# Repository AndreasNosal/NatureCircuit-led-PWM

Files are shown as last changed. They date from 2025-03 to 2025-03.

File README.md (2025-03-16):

# Mobile-Controlled Light

This project showcases a light fixture that can be controlled remotely via a smartphone (using ESP32 and BLE/Wi-Fi). The device is designed for flexible operation and easy assembly, making it suitable for a wide range of DIY enthusiasts or educational projects. By incorporating a custom PCB, an LED panel, and 3D-printed parts, you can create a smart lighting system that connects seamlessly to your mobile phone.

Originally designed to help users learn about PCB assembly, soldering techniques, and microcontroller programming, this project emphasizes a hands-on approach. Whether you order your PCBs from JLCPCB and print your own stencil for the LED panel or simply 3D-print the housing at home, you’ll gain valuable experience in hardware assembly and coding for an IoT-focused device.

Our webside for instructions: https://nature-circuit.tech/courses

## Features
- **ESP32-Based Controller**: Uses two main files (`main.py` and `ble_advertising.py`) to establish a reliable Bluetooth connection for receiving commands from your smartphone.
- **LED Panel**: Powered by an optional custom PCB or a standard LED strip; easily replaceable or upgradable.
- **3D-Printable Enclosure**: Designed for FDM printing with minimal supports. Can also be adapted to various 3D printers.
- **Scalable Assembly**: Choose between ordering a stencil for solder paste application or printing your own with a standard 3D printer.
- **Easy Soldering**: Ideal for beginners; the main PCB has through-hole or straightforward SMD components, and the layout is beginner-friendly.
- **Flexible Power Input**: Operates on typical USB power or a regulated supply (e.g., 5V).  

## Getting Started
1. **Gather Materials**: Order or produce the main PCB (recommended via JLCPCB) and LED panel. If you own a 3D printer, you can create the stencil for solder paste application.  
2. **Print Enclosure**: Use your preferred 3D printer and slicer settings (e.g., minimal supports). PLA or PETG are commonly used filaments.  
3. **Solder Components**: Prepare your soldering iron (typically 320–350 °C). Follow the silkscreen labels on the PCB and reference any documentation or schematics for correct polarity and placement.  
4. **Program the ESP32**:  
   - Upload `main.py` and `ble_advertising.py` to the ESP32 board.  
   - `main.py` runs automatically on reboot.  
   - `ble_advertising.py` enables BLE connectivity so the device can receive commands.  
5. **Assemble & Power Up**: Once everything is in place, provide power (5V recommended), and check the device’s functionality by connecting with your mobile phone.

## Usage
- **Mobile App Connection**: Use a compatible app (or custom-developed one) to scan and connect via BLE.  
- **Light Control**: Toggle the light on/off or adjust brightness (if supported).  
- **Firmware Updates**: Modify `main.py` for custom behavior, color transitions, scheduling, or advanced IoT integration.

## License
- Under **GPL-3.0** license.

## Example in Action
led-box-preview-video

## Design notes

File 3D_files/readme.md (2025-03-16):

# 3D Files for PWM-Light

This folder contains the **3D models** (Fusion 360 design files, STL exports, and any additional resources) used to create the enclosure or other mechanical parts for the **PWM-light** project. The models are designed to be **FDM-friendly**, requiring minimal supports, and are easily adaptable for various 3D printers and use cases.

## Contents

- **Fusion 360 Source Files**  
  - Editable design files for further enhancements or customizations. If you need to change dimensions, mounting points, or aesthetics, simply open these in Autodesk Fusion 360 (or a compatible CAD tool) and modify as needed.

- **STL Files**  
  - Ready-to-print mesh files exported from the Fusion 360 models. These can be opened in your preferred slicing software (e.g., PrusaSlicer, Cura, Simplify3D) to generate G-code for your 3D printer.

- **Additional Docs/Images (if provided)**  
  - Any reference pictures, exploded views, or supplementary instructions specific to assembling the printed parts.
Meteo_box_2025-Mar-16_04-50-34PM-000_CustomizedView15039672676

## Printing Recommendations

- **Minimal Supports**: The models are structured to minimize or even eliminate the need for supports, saving on material and print time.
- **Material Choice**:  
  - **PLA** is a common choice for indoor use, providing ease of printing and cost-effectiveness.  
  - **PETG** is recommended if you need more heat or impact resistance.
- **Infill & Perimeters**: Adjust infill percentage and perimeter count based on your durability requirements. For typical enclosures, an **infill of 10–20%** and 2–3 perimeters often suffice.

## Assembly Notes

1. **Mounting Hardware**: In most cases, M3 screws or self-tapping screws are used to secure boards, panels, or lids.  
2. **Access to Ports & Vents**: Ensure your final print properly aligns with cutouts for cables, power, or ventilation.  
3. **Combining with Electronics**: This enclosure is specifically designed for the **PWM-light** PCB and related components as described in the main repository. However, you can also adapt it for other electronics if needed.

## Modifying the Design

- The **Fusion 360** files are provided for easy editing.  
- Feel free to **remix** the enclosure to fit different boards, additional sensors, or custom cutouts.  
- If you improve or redesign the models, consider contributing your modifications back to this project!

## Usage & License

- These design files are offered under the **GPL-3.0** license, similar to the rest of the project.  
- You’re free to share, modify, and build upon the designs, as long as you provide the same freedoms to others and acknowledge the original source.
obrázok

---

Enjoy bringing the **PWM-light** enclosure to life! If you encounter any issues during printing or assembly, check the [main documentation](../README.md) or open an issue in the repository. Contributions and feedback are always welcome.

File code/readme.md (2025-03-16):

# PWM-Light Firmware

This repository contains **MicroPython** files for driving a PWM-based light (LED or MOSFET output) via Bluetooth Low Energy (BLE) on **ESP32-C3** microcontrollers. It demonstrates how to advertise and receive BLE messages to control the brightness level or simple on/off actions for connected LEDs.

## Repository Contents

1. **`ble_advertising.py`**  
   - A helper library that enables the ESP32-C3 to broadcast its presence via BLE. It handles the fundamental advertising payload necessary for BLE connections.
2. **`pwm-led-ESP32_C3_SuperMini.py`**  
   - A MicroPython script optimized for the **ESP32-C3 SuperMini** board.  
   - Assigns GPIO pins specific to this board and sets up BLE-based UART to receive commands (e.g., "ON", "OFF", or brightness values).
3. **`pwm-led-Seed-Studio-C3.py`**  
   - A nearly identical MicroPython script for the **Seed-Studio ESP32-C3** board.  
   - The main difference lies in the assigned GPIO pins for the RGB LEDs, MOSFET driver, and optional buzzer.

## How It Works

### BLE Peripheral Setup
Both `pwm-led-ESP32_C3_SuperMini.py` and `pwm-led-Seed-Studio-C3.py` create a **BLESimplePeripheral** instance, which:
- Advertises itself under the name `PWM-LED`.
- Exposes two UART-like characteristics (`RX` and `TX`) so a smartphone or computer can connect via BLE and exchange data.

The advertising functionality is implemented with the help of **`ble_advertising.py`**, which constructs the BLE packets announcing the device’s presence. Once a central device (such as a phone) connects:
- **Writes** to the `RX` characteristic are received by the script (`on_write` callback).
- **Notifications** for the `TX` characteristic can be used to send data back to the central device if needed.

### Command Parsing
Incoming data is decoded in `on_rx(value)`, where text commands are expected:
- `ON` turns on the MOSFET (or LED) at either full brightness or a previously set brightness level.
- `OFF` switches the MOSFET (or LED) fully off.
- Numeric values between **0** and **100** set the duty cycle, effectively controlling brightness (`0`% = off, `100`% = maximum).

### PWM Output & Pin Definitions
- A dedicated **PWM** object controls the MOSFET pin, allowing partial or full brightness adjustments.
- Additional **PWM** objects handle an **RGB LED** (three separate channels for red, green, and blue). These enable pulse/breathing effects while advertising or responding to connection status.
- **Buzzer** feedback:
  - A short ascending tone indicates a **new connection**.
  - A short descending tone indicates a **disconnection**.

### Differences in Board Scripts
The **ESP32-C3 SuperMini** and **Seed-Studio ESP32-C3** boards share similar functionality, but differ in **GPIO pin assignments**:
- `pwm-led-ESP32_C3_SuperMini.py` uses pin constants (`buzzer_gpio`, `mosfet_gpio`, etc.) suitable for the SuperMini layout.
- `pwm-led-Seed-Studio-C3.py` adjusts these pin values for the Seed-Studio layout.

## Getting Started

1. **Set Up MicroPython**:  
   - Flash a MicroPython firmware compatible with your ESP32-C3 board.

2. **Upload Files**:  
   - Use a tool such as **Thonny**, **uPyCraft**, or the **ampy** CLI to upload:
     - `ble_advertising.py`
     - The relevant PWM script for your board:
       - `pwm-led-ESP32_C3_SuperMini.py` **or**  
       - `pwm-led-Seed-Studio-C3.py`
   - Make sure both files reside in the device’s root filesystem.  
   - You may rename the chosen script to `main.py` so it runs on startup, or manually call it from the REPL.

3. **Power the Board**:  
   - Provide a suitable 5V supply (or 3.3V if your board includes a regulator).  
   - Ensure any connected LED strip, MOSFET, or RGB LED is wired properly.

4. **Connect via BLE**:
   - On your smartphone, open a BLE UART app or a custom app.  
   - Find and connect to the device named `PWM-LED`.  
   - Once connected, send commands like `ON`, `OFF`, or a number from `0` to `100`.

5. **Test and Modify**:
   - Observe LED brightness changes and buzzer feedback on connection/disconnection.  
   - Adjust code in the script for custom effects or different pin mappings.

## Example Commands

- **`ON`**: Turn on the LED/MOSFET at the last known brightness level or full.  
- **`OFF`**: Switch off the LED/MOSFET entirely.  
- **`50`**: Set the LED brightness to 50% (half duty cycle).  

## License
- Under **GPL-3.0** license.

## Further Customizations
- **RGB Effects**: Modify `pulse()` or `blink()` methods in the `RGBleds` class for unique lighting animations.  
- **Buzzer Sounds**: Customize the tones in `sound_connect()` or `sound_disconnect()` for unique connection alerts.  
- **Pin Mapping**: Change the pin constants at the top of each script if you use different GPIO lines or want to port the code to another board.

---  

Enjoy controlling your PWM-based lighting system via BLE! Contributions and suggestions are always welcome.

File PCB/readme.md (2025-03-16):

# PWM-Light PCB

This repository contains the PCB design files and documentation for a **PWM-based light control module**. By using a dedicated PCB, you can drive LEDs or other lighting elements with precise brightness control via PWM (Pulse Width Modulation). The board is ideal for DIY projects, educational use, or as a foundation for more advanced smart-lighting solutions.



## Overview
- **KiCad Design**: The PCB is designed in KiCad (including schematic and layout).  
- **PWM Output**: Provides efficient dimming capability for LED arrays or single LEDs with minimal flicker.  
- **ESP32 or Other Microcontrollers**: Compatible with 3.3V logic devices (e.g., ESP32, STM32, Arduino Pro Mini at 3.3V, etc.) for easy integration into IoT or custom home-automation setups.  
- **Power Handling**: Designed to be supplied from a stable 5V source (or other voltages, depending on your chosen components and regulator configuration).  
- **JLCPCB Manufacturing**: Gerber files are ready to upload to PCB manufacturers (e.g., JLCPCB).  

## Features
- **Compact Layout**: Minimal footprint for easy integration into small enclosures.  
- **Adjustable Voltage Regulation**: Option to include a regulator if powering from higher than 5V.  
- **Through-Hole & SMD Mix**: Balanced design for straightforward soldering—newcomers can assemble basic sections while advanced users can integrate SMD parts for improved performance.  
- **Expansion Headers**: Multiple I/O pins (PWM, I2C, SPI, etc.) broken out for adding sensors or additional modules.

## Getting Started

1. **Download or Clone the Repository**  
   - Access the KiCad project files and Gerber exports from this repository.

2. **Customize the Design (Optional)**  
   - If you want different connectors, pinouts, or layout modifications, edit the schematic and PCB layout in KiCad.  
   - Generate new Gerber files if you make changes.

3. **Order the PCB**  
   - Upload the provided Gerber files to a PCB manufacturer such as JLCPCB.  
   - Choose your PCB specifications (layer count, color, thickness, etc.).  
   - Wait for the boards to be manufactured and shipped.



4. **Assemble the Components**  
   - Refer to the schematic/BoM (Bill of Materials) for correct part placement.  
   - Solder the components using standard soldering techniques.  
     - For SMD parts, you may use solder paste and a reflow method (hot plate, reflow oven, or hot air gun).  
     - For through-hole parts, use a temperature of around 320–350 °C and ensure solid, shiny joints.

5. **Program & Connect**  
   - If using an ESP32 or similar microcontroller, attach it to the board’s headers or pads.  
   - Upload your firmware (e.g., Arduino, MicroPython) to control PWM signals and logic.  
   - Power the board with a stable 5V supply (or according to your regulator setup).

6. **Test & Calibrate**  
   - Connect an LED array or single LED to the PWM output pins.  
   - Vary the duty cycle in your code to confirm proper dimming functionality.  
   - Check power consumption, heat dissipation, and general performance.

## Usage Scenarios
- **Smart Lighting**: Combine with a Bluetooth or Wi-Fi module for mobile app control.  
- **DIY Projects**: Enhance desk lamps, ambient room lighting, or artistic LED installations.  
- **Educational**: Demonstrate PWM principles and advanced lighting control in classroom or workshop settings.

## License
- Licensed under the **GPL-3.0** License.
> *Feel free to share improvements or fork this project to fit your specific needs. Contributions are welcome!*

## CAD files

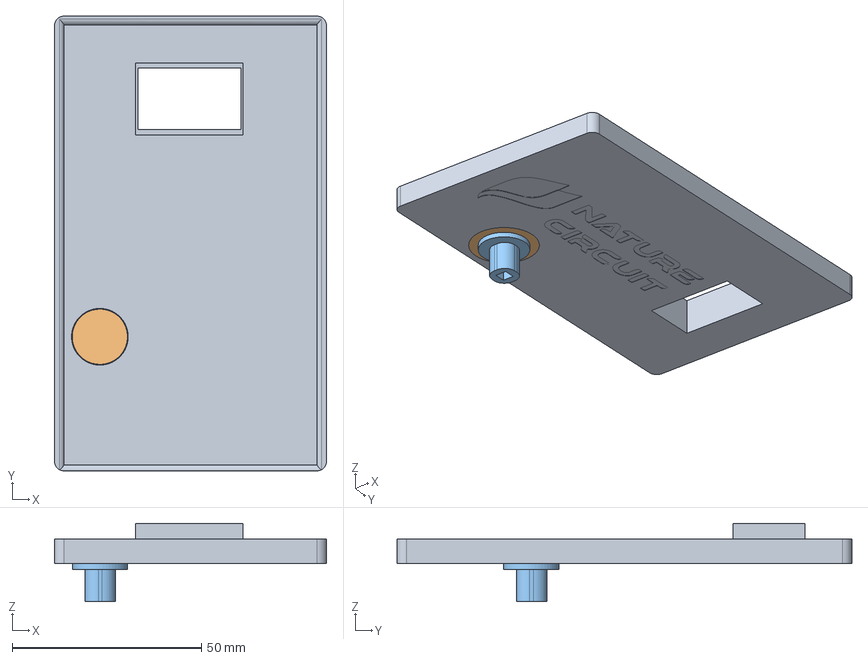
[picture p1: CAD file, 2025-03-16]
3D_files/LED_BOX_top v29.step
71.9 x 120.2 x 20.6 mm

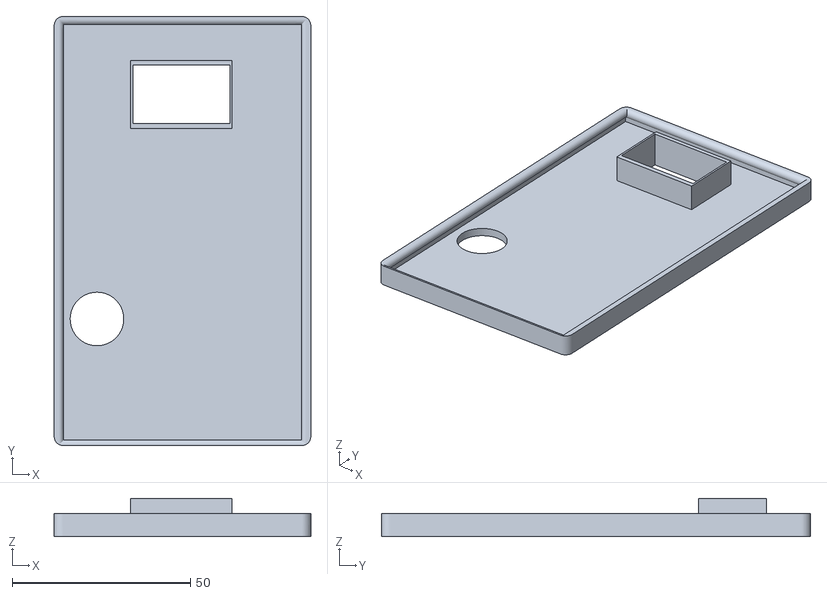
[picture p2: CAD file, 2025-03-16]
3D_files/parts_stls/body_top.stl
71.9 x 120.2 x 10.6

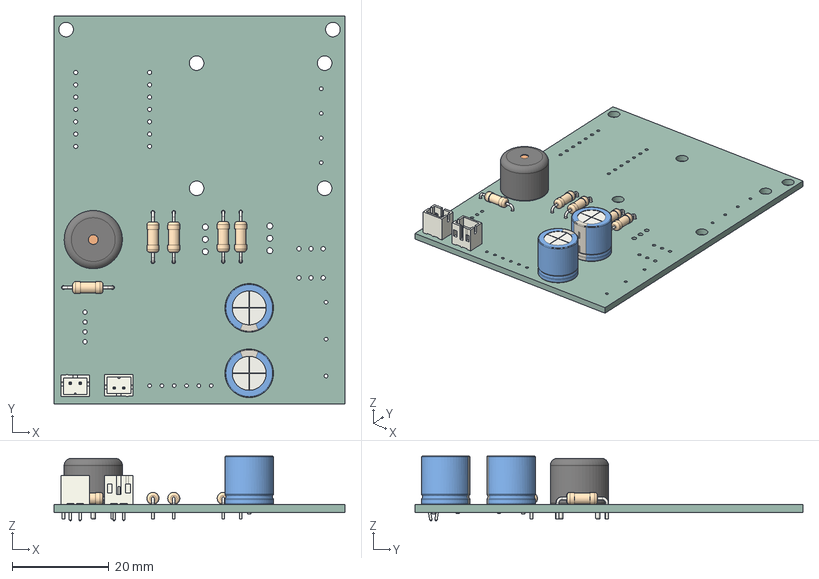
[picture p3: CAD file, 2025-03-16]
PCB/LED-board/LED-board-PWM.step
60.0 x 80.0 x 13.4 mm
JST_B2B_PH_K x 2
R_Axial_DIN0207_L63mm_D25mm_P1016mm_Horizontal x 5
Buzzer_12x95RM76
CP_Radial_D100mm_P500mm x 2
LED-board-PWM_PCB

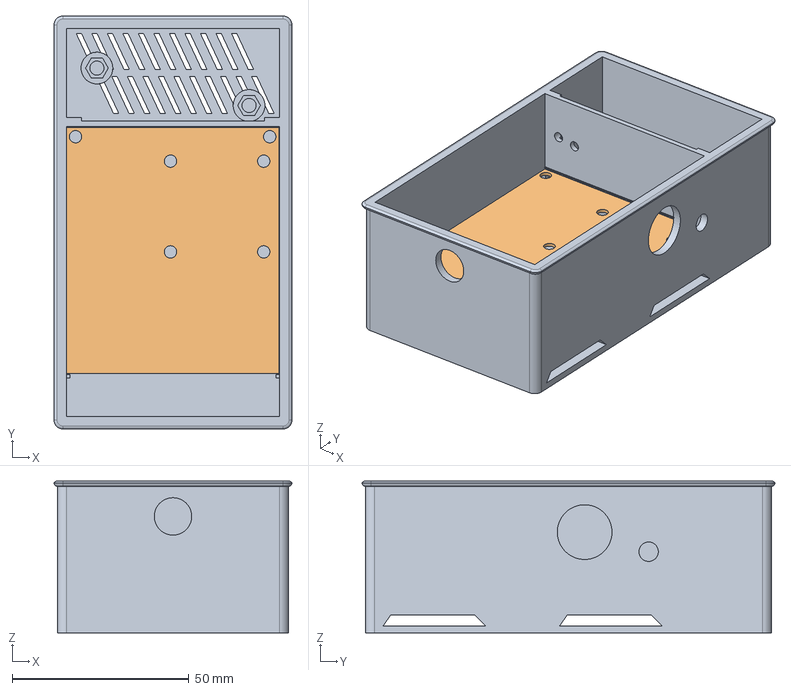
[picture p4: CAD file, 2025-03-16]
3D_files/LED_BOX_bottom v31.step
67.4 x 117.0 x 43.0 mm

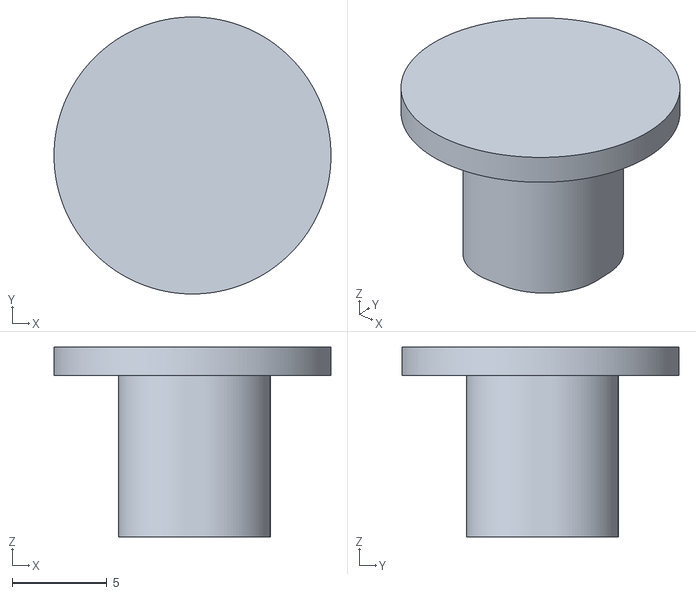
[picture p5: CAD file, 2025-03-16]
3D_files/parts_stls/button_cover.stl
14.6 x 14.6 x 10.0

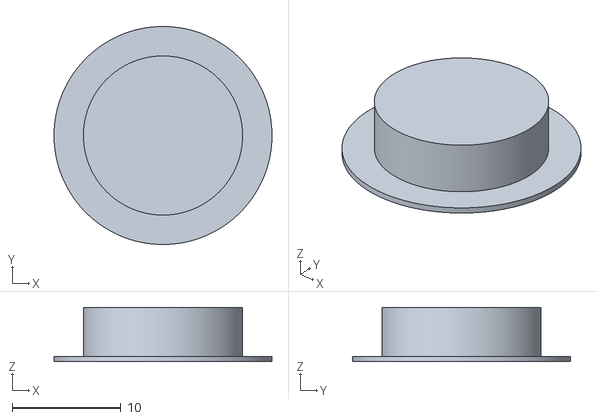
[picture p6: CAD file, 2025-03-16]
3D_files/parts_stls/button.stl
20.0 x 20.0 x 5.00

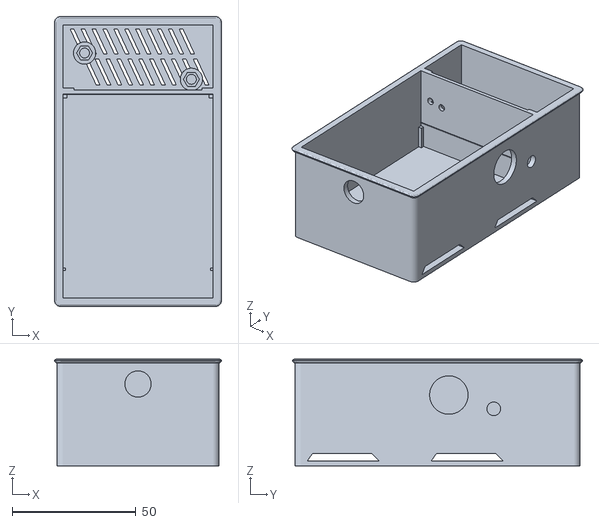
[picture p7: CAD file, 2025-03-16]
3D_files/parts_stls/Box_bottom.stl
67.4 x 117.0 x 43.0

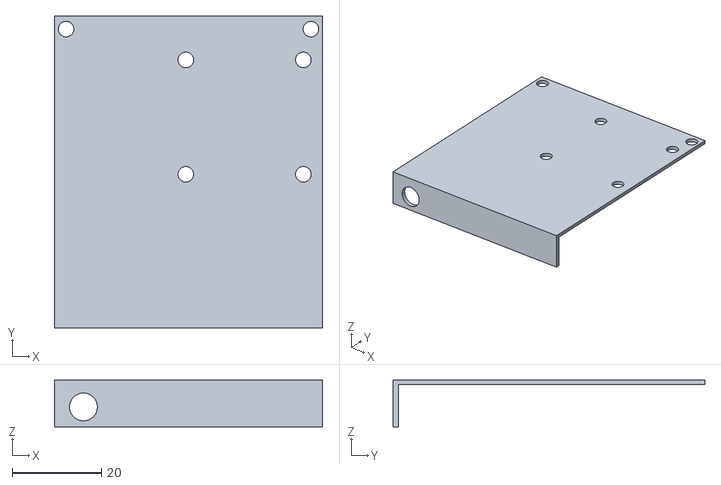
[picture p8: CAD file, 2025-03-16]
3D_files/parts_stls/Cover_lithium_battery.stl
60.2 x 70.0 x 10.6

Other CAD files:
3D_files/LED_BOX_bottom v31.f3d
3D_files/LED_BOX_bottom v31.ipt
3D_files/LED_BOX_top v29.f3d
3D_files/LED_BOX_top v29.ipt

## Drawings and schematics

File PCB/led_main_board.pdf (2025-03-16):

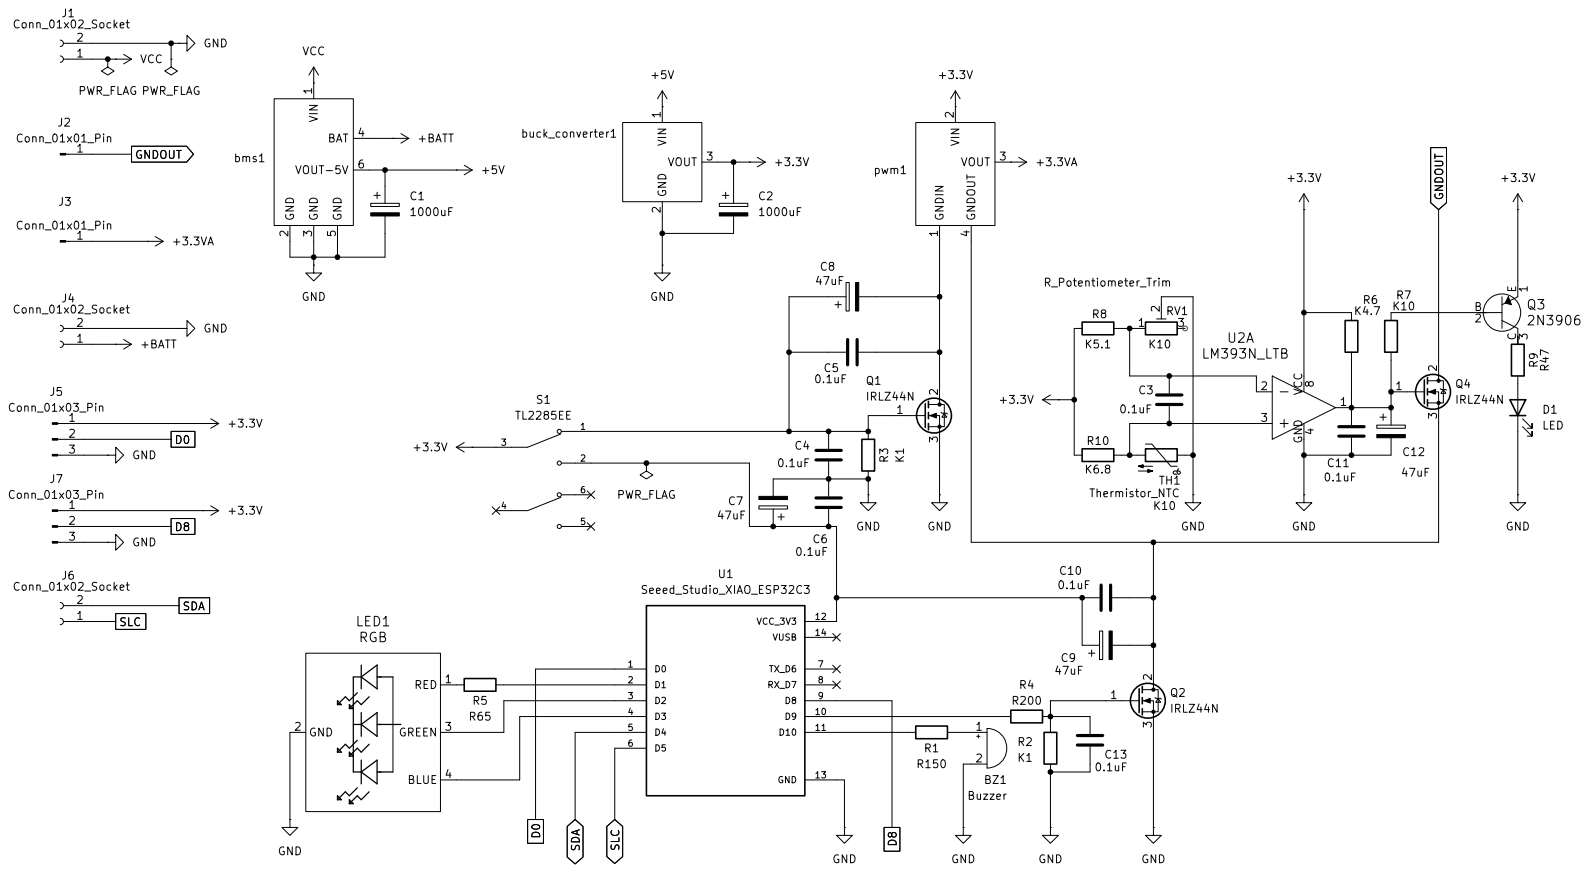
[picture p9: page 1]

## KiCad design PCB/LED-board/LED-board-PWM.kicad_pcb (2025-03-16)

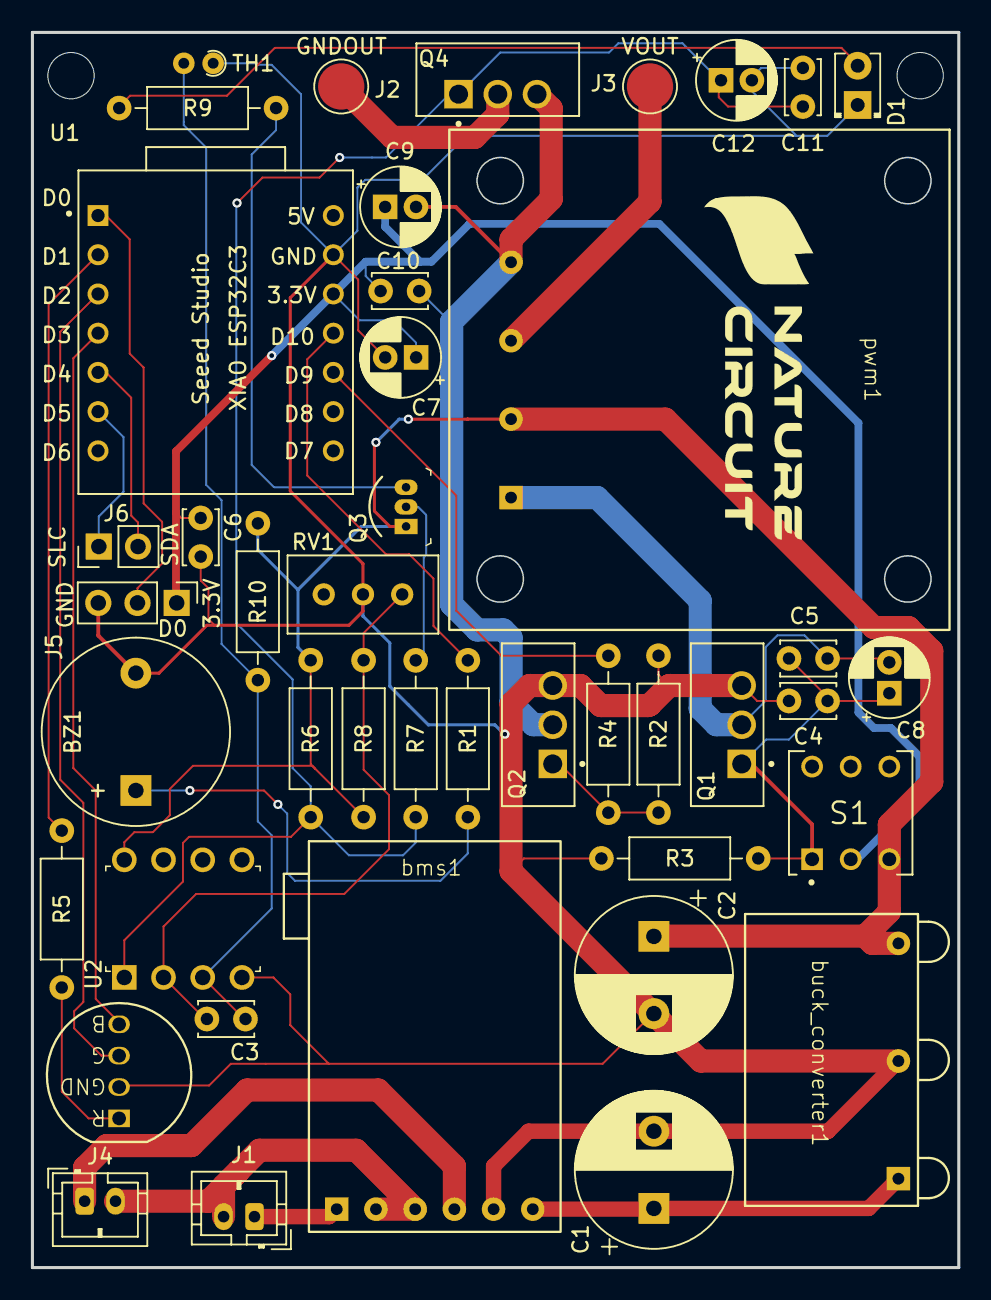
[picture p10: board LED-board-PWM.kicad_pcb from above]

Board: 2 copper layers, 60.0 x 80.0 mm, 43 parts (0 on the bottom side), 28 nets.

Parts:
BZ1: Buzzer; Buzzer_12x9.5RM7.6
C1, C2: 1000uF; CP_Radial_D10.0mm_P5.00mm
C3, C4, C5, C6, C10, C11: 0.1uF; C_Disc_D3.4mm_W2.1mm_P2.50mm
C7, C8, C9, C12: 47uF; CP_Radial_D5.0mm_P2.00mm
D1: LED; LED_D2.0mm_W4.0mm_H2.8mm_FlatTop
J1, J4: Conn_01x02_Socket; JST_PH_B2B-PH-K_1x02_P2.00mm_Vertical
J2, J3: Conn_01x01_Pin; TestPoint_Pad_D3.0mm
J5: Conn_01x03_Pin; PinHeader_1x03_P2.54mm_Vertical
J6: Conn_01x02_Socket; PinHeader_1x02_P2.54mm_Vertical
LED1: RGB; RGB_LED
Q1, Q2, Q4: IRLZ44N
Q3: 2N3906; TO-92-3
R1: R150; R_Axial_DIN0207_L6.3mm_D2.5mm_P10.16mm_Horizontal
R2, R3, R7: K10; R_Axial_DIN0207_L6.3mm_D2.5mm_P10.16mm_Horizontal
R4: R200; R_Axial_DIN0207_L6.3mm_D2.5mm_P10.16mm_Horizontal
R5: R65; R_Axial_DIN0207_L6.3mm_D2.5mm_P10.16mm_Horizontal
R6: K4.7; R_Axial_DIN0207_L6.3mm_D2.5mm_P10.16mm_Horizontal
R8: K5; R_Axial_DIN0207_L6.3mm_D2.5mm_P10.16mm_Horizontal
R9: R50; R_Axial_DIN0207_L6.3mm_D2.5mm_P10.16mm_Horizontal
R10: K7; R_Axial_DIN0207_L6.3mm_D2.5mm_P10.16mm_Horizontal
RV1: R_Potentiometer_Trim; Potentiometer_Bourns_3296W_Vertical
S1: TL2285EE; SW_TL2285EE
TH1: Thermistor_NTC; R_Axial_DIN0204_L3.6mm_D1.6mm_P1.90mm_Vertical
U1: Seeed_Studio_XIAO_ESP32C3; MODULE_Seeed_Studio_XIAO_ESP32C3
U2: LM393N_LTB; DIP-8_W7.62mm
bms1: MH_CD42_Charge_Discharge_Module
buck_converter1: TZT_4A_Mini_DC_DC_Buck_Converter
pwm1: PWM_regulator_2A

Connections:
BAT: J4.1, bms1.4 (BAT)
D0: J5.2, U1.1 (D0)
ESP32-3.3V: C6.1, C7.1, C9.1, C10.2, J5.1, S1.2, U1.12 (VCC_3V3)
GND: BZ1.2 (-), C1.2, C2.2, C4.2, C6.2, C7.2, C11.2, C12.2, D1.1 (K), J1.2, J4.2, J5.3, LED1.2 (GND), Q1.3, Q2.3, R2.1, R3.1, RV1.2, TH1.1, U1.13 (GND), U2.4 (GND), bms1.2 (GND), bms1.3 (GND), bms1.5 (GND), buck_converter1.2 (GND)
GNDOUT: J2.1, Q4.2
unnamed: BZ1.1 (+), R1.2
unnamed: C3.1, R8.2, RV1.1, U2.2
unnamed: C3.2, R10.1, TH1.2, U2.3
unnamed: C4.1, C5.1, C8.1, Q1.1, R3.2, S1.1
unnamed: C11.1, C12.1, Q4.1, R6.1, R7.1, U2.1
unnamed: D1.2 (A), R9.1
unnamed: LED1.4 (BLUE), U1.4 (D3)
unnamed: LED1.3 (GREEN), U1.3 (D2)
unnamed: LED1.1 (RED), R5.1
unnamed: Q2.1, R2.2, R4.1
unnamed: Q3.2 (B), R7.2
unnamed: Q3.3 (C), R9.2
unnamed: R5.2, U1.2 (D1)
unnamed: R4.2, U1.10 (D9)
unnamed: R1.1, U1.11 (D10)
unnamed: C5.2, C8.2, Q1.2, pwm1.1 (GNDIN)
unnamed: C9.2, C10.1, Q2.2, Q4.3, pwm1.4 (GNDOUT)
SDA: J6.2, U1.5 (D4)
SLC: J6.1, U1.6 (D5)
VIN: J1.1, bms1.1 (VIN)
VOUT: J3.1, pwm1.3 (VOUT)
VOUT-3.3: C2.1, Q3.1 (E), R6.2, R8.1, R10.2, S1.3, U2.8 (VCC), buck_converter1.3 (VOUT), pwm1.2 (VIN)
VOUT-5: C1.1, bms1.6 (VOUT-5V), buck_converter1.1 (VIN)

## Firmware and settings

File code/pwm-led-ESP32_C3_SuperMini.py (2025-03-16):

# This is a UART periperhal.

import bluetooth
from ble_advertising import advertising_payload
from micropython import const
import machine
import time
from math import log

_IRQ_CENTRAL_CONNECT = const(1)
_IRQ_CENTRAL_DISCONNECT = const(2)
_IRQ_GATTS_WRITE = const(3)

_FLAG_READ = const(0x0002)
_FLAG_WRITE_NO_RESPONSE = const(0x0004)
_FLAG_WRITE = const(0x0008)
_FLAG_NOTIFY = const(0x0010)

_UART_UUID = bluetooth.UUID("6E400001-B5A3-F393-E0A9-E50E24DCCA9E")
_UART_TX = (
    bluetooth.UUID("6E400003-B5A3-F393-E0A9-E50E24DCCA9E"),
    _FLAG_READ | _FLAG_NOTIFY,
)
_UART_RX = (
    bluetooth.UUID("6E400002-B5A3-F393-E0A9-E50E24DCCA9E"),
    _FLAG_WRITE | _FLAG_WRITE_NO_RESPONSE,
)
_UART_SERVICE = (
    _UART_UUID,
    (_UART_TX, _UART_RX),
)

class BLESimplePeripheral():
    def __init__(self, ble, name="mpy-uart"):
        self._ble = ble
        self._ble.active(True)
        self._ble.irq(self._irq)
        ((self._handle_tx, self._handle_rx),) = self._ble.gatts_register_services((_UART_SERVICE,))
        self._connections = set()
        self._write_callback = None
        self._payload = advertising_payload(name=name, services=[_UART_UUID])
        self._connected = False
        self._advertising = False
        self._advertise()

    def _irq(self, event, data):
        # Track connections so we can send notifications.
        if event == _IRQ_CENTRAL_CONNECT:
            conn_handle, _, _ = data
            self._connected = True
            self._advertising = False
            self._connections.add(conn_handle)
        elif event == _IRQ_CENTRAL_DISCONNECT:
            conn_handle, _, _ = data
            self._connected = False
            self._connections.remove(conn_handle)
            # Start advertising again to allow a new connection.
            self._advertise()
        elif event == _IRQ_GATTS_WRITE:
            conn_handle, value_handle = data
            value = self._ble.gatts_read(value_handle)
            if value_handle == self._handle_rx and self._write_callback:
                self._write_callback(value)

    def send(self, data):
        for conn_handle in self._connections:
            self._ble.gatts_notify(conn_handle, self._handle_tx, data)

    def is_connected(self):
        return len(self._connections) > 0

    def _advertise(self, interval_us=500000):
        self._ble.gap_advertise(interval_us, adv_data=self._payload)
        self._advertising = True

    def on_write(self, callback):
        self._write_callback = callback
        
    def get_connected(self):
        return self._connected
    
    def get_advertising(self):
        return self._advertising
        
#
# RGB led class
#

class RGBleds():
    def __init__(self, leds):
        self.leds = leds
        self.max_value = const(65535)
        self.min_value = const(0)
        self.current_red = self.max_value
        self.current_green = self.max_value
        self.current_blue = self.max_value
    
    def pulse(self, duration, red_duty=0, green_duty=0, blue_duty=0):
        brightness = self.max_value
        state = -1
        for _ in range(2):
            state *= -1
            for j in range(63):
                brightness = brightness - (1000 * state)
                red_multiplier = red_duty 		/ self.max_value
                green_multiplier = green_duty 	/ self.max_value
                blue_multiplier = blue_duty 	/ self.max_value
                for led in self.leds:
                    self.change_RGB(
                        int(red_multiplier 		* brightness),
                        int(green_multiplier 	* brightness),
                        int(blue_multiplier 	* brightness))
                time.sleep_ms(duration)

    def blink(self, duration, red_duty=0, green_duty=0, blue_duty=0):
        switch = True
        for _ in range(2):
            switch = not switch
            for led in leds:
                self.change_RGB(
                    red_duty 	* switch,
                    green_duty 	* switch,
                    blue_duty 	* switch)
            time.sleep_ms(duration)
            
    def change_RGB(self, red_duty, green_duty, blue_duty):
        for ledDuty, led in zip((red_duty, green_duty, blue_duty), self.leds):
            led.init(freq = 2000, duty_u16 = ledDuty)
        self.current_red 	= red_duty
        self.current_green 	= green_duty
        self.current_blue 	= blue_duty
        
    def on(self):
        self.change_RGB(self.current_red, self.current_green, self.current_blue)
        
    def off(self):
        self.change_RGB(self.min_value, self.min_value, self.min_value)
        
#
# Functions for PWM-LED
#

def on_rx(value):
    global rx_message
    value = value.decode("strict").replace("\r\n","")
    rx_message = value
    print("RX", rx_message)
    
def is_number(input_value):
    try:
        if input_value == "0":
            return 0
        int_value = int(input_value)
        return int_value
    except ValueError:
        pass
    return None

def play_tone(buzzer, freq, duration, pause = 0):
        buzzer.init(freq = freq, duty_u16 = 2**15)
        time.sleep_ms(duration)
        buzzer.duty_u16(0)
        time.sleep_ms(pause)
        
def sound_connect(buzzer):
    for freq_increment in range(2000, 6000, 1000):
        play_tone(buzzer = buzzer, freq = freq_increment, duration = 150)

def sound_disconnect(buzzer):
    for freq_increment in range(0, 4000, 3000):
        play_tone(buzzer = buzzer, freq = 5000 - freq_increment, duration = 150)
    
def set_device_duty(device, duty, freq = 2000):
    device.init(duty = duty, freq = freq)
    
def set_duty_to_maximum(device, freq = 2000):
    set_device_duty(device, duty = 1023, freq = freq)

def set_duty_to_minimum(device, freq = 2000):
    set_device_duty(device, duty = 0,  freq = freq)

#
# Main for PWM-LED
#
buzzer_gpio = const(10)
mosfet_gpio = const(9)
red_led_gpio = const(3)
green_led_gpio = const(4)
blue_led_gpio = const(5)

buzzer 		= 	machine.PWM(machine.Pin(buzzer_gpio, machine.Pin.OUT))
mosfet 		= 	machine.PWM(machine.Pin(mosfet_gpio, machine.Pin.OUT))
red_led 	= 	machine.PWM(machine.Pin(red_led_gpio, machine.Pin.OUT))
green_led 	= 	machine.PWM(machine.Pin(green_led_gpio, machine.Pin.OUT))
blue_led 	= 	machine.PWM(machine.Pin(blue_led_gpio, machine.Pin.OUT))

buzzer.deinit()
mosfet.deinit()
red_led.deinit()
green_led.deinit()
blue_led.deinit()

rgb_leds = RGBleds(leds = (red_led, green_led, blue_led))

ble = bluetooth.BLE()
bluethooth = BLESimplePeripheral(ble, name = "PWM-LED")
rx_message = None
bluethooth.on_write(on_rx)

previous_connected = False
previous_advertising = False
previous_duty = None

while True:
    if bluethooth.get_connected() and not previous_connected:
        previous_connected = True
        print("Device is connected")
        sound_connect(buzzer)
        
    elif not bluethooth.get_connected() and previous_connected:
        previous_connected = False
        print("Device is disconnected")
        sound_disconnect(buzzer)
        
    if bluethooth.get_advertising() and not previous_advertising:
        previous_advertising = True
        print("Starting advertising")
        set_duty_to_minimum(device = mosfet)
        previous_duty = None
        
    elif not bluethooth.get_advertising() and previous_advertising:
        previous_advertising = False
        print("Ending advertising")
        rgb_leds.change_RGB(red_duty = 5000, green_duty = 4000, blue_duty = 20000)
    
    if previous_advertising:
        rgb_leds.pulse(duration = 20, red_duty = 5000, green_duty = 4000, blue_duty = 20000)
        
    
    if not rx_message:
        time.sleep_ms(100)
        continue
    
    if rx_message == "ON":
        if not previous_duty:
            set_duty_to_maximum(device = mosfet)
        else:
            set_device_duty(device = mosfet, duty = previous_duty)
            
        print("Turning on the LED")
        rx_message = None
        continue
    
    if rx_message == "OFF":
        set_duty_to_minimum(device = mosfet)
        print("Turning off the LED")
        rx_message = None
        continue

    rx_number = is_number(rx_message)
    if rx_number and rx_number <= 100 and rx_number >= 0:
         duty = int(round(10.23 * rx_number))
         previous_duty = duty
         set_device_duty(device = mosfet, duty  = duty)
         print("Duty set to:", duty)
         rx_message = None

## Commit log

2025-03-16 Added chematic for led-pwm main board
2025-03-16 Added Kicad files
    [LED-board-PWM.kicad_pcb, LED-board-PWM.kicad_sch, LED-board-PWM.step]
2025-03-16 Gerber files for production
2025-03-16 Added gerber files for production JLCPCB
    [LED-board-PWM-B_Cu.gbl, LED-board-PWM-B_Mask.gbs, LED-board-PWM-B_Paste.gbp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]
2025-03-16 Added files for the led-pwm
2025-03-16 Addded all 3D files
    [Box_bottom.stl, Cover_lithium_battery.stl, LED_BOX_bottom v31.f3d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]
